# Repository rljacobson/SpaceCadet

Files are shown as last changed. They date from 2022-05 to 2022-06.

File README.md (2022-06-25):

# Space Cadet Keyboard Schematic and PCB

This repo contains [KiCAD](https://www.kicad.org/) source files and generated gerber files for the ["Space Cadet" keyboard](https://en.wikipedia.org/wiki/Space-cadet_keyboard), reverse engineered from reference photos in May 2022. To my knowledge, this is the first and only reproduction of this keyboard in EDA form.

### Variants

The board comes in three flavors: 

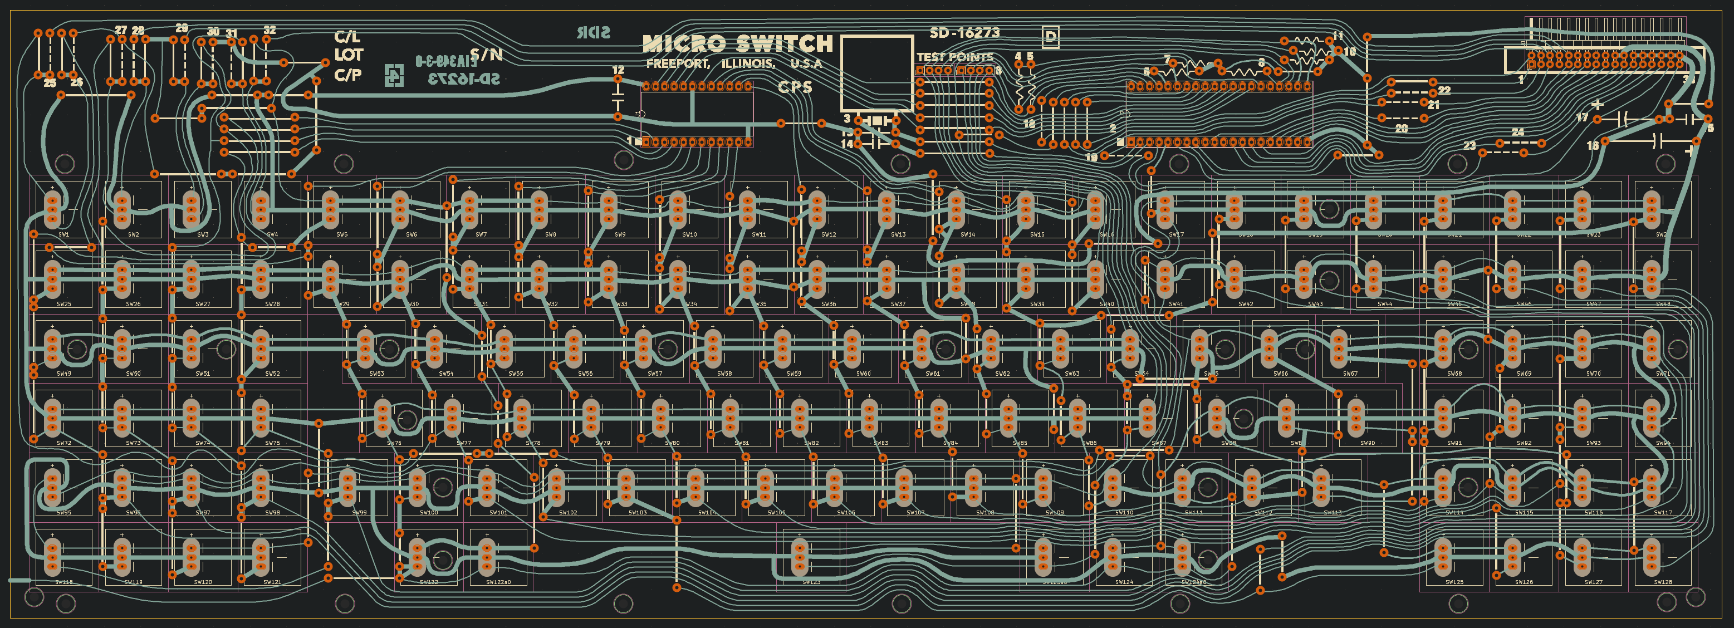
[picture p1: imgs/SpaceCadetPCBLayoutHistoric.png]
PCB Layout Historic
1. **Main branch:** An attempt at a faithful reproduction of the historic hand-drawn PCB. 
2. **Modern:** The board retains the original topology, and the footprints are in the original positions, but everything is drawn in the style of a modern PCB. 
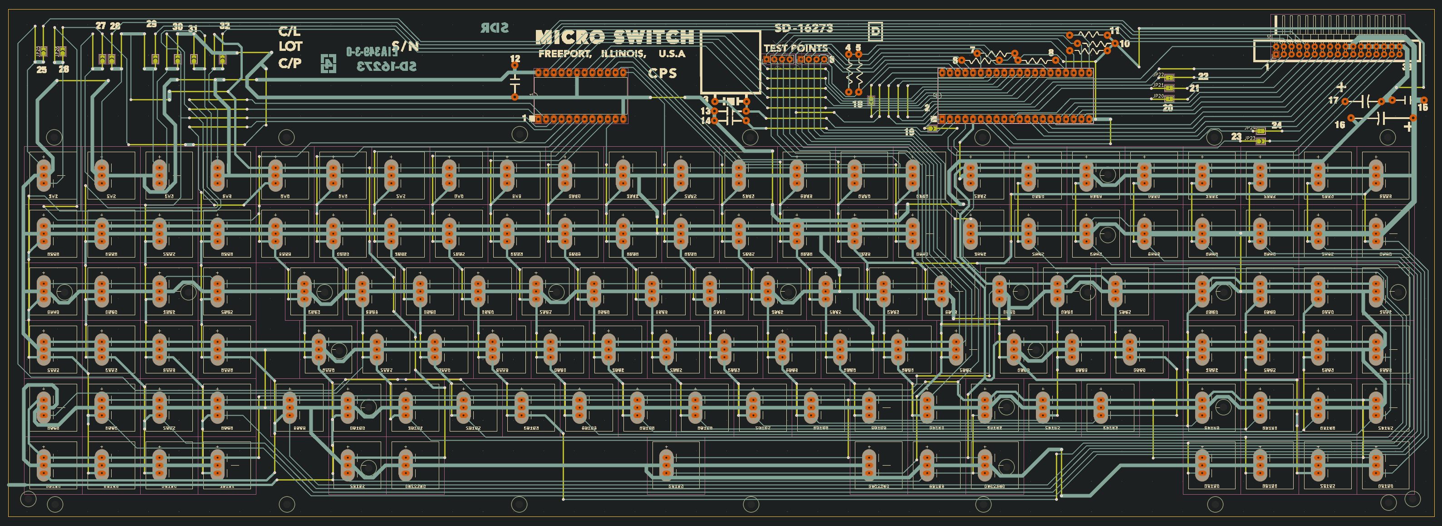
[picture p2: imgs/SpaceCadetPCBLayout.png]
SpaceCadetPCBLayout
   
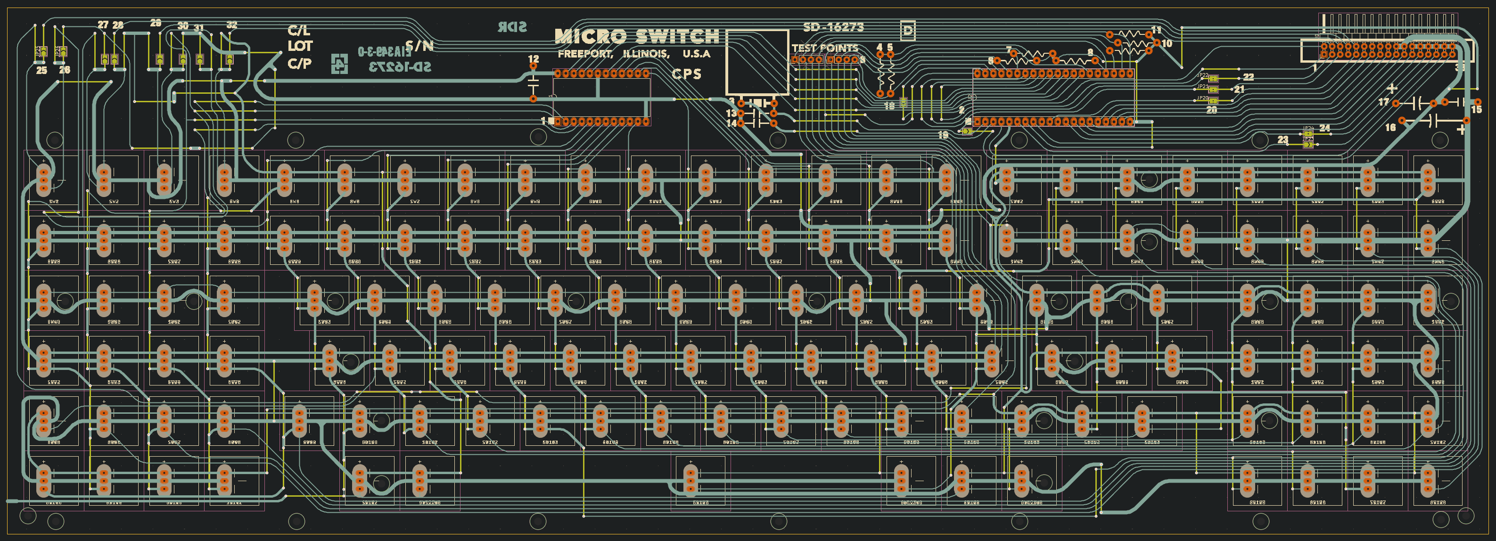
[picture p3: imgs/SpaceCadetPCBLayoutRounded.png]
SpaceCadetPCBLayoutRounded
3. **Modern Rounded:** The modern version processed with the *Round Tracks* plugin for KiCAD, which gives the board a hand-drawn aesthetic. 

Variations #2 and #3 are in the Modern branch.

### Reference Material

The design files were reverse engineered from a variety of reference materials. As quality reference materials were hard to get ahold of, I also include them here:

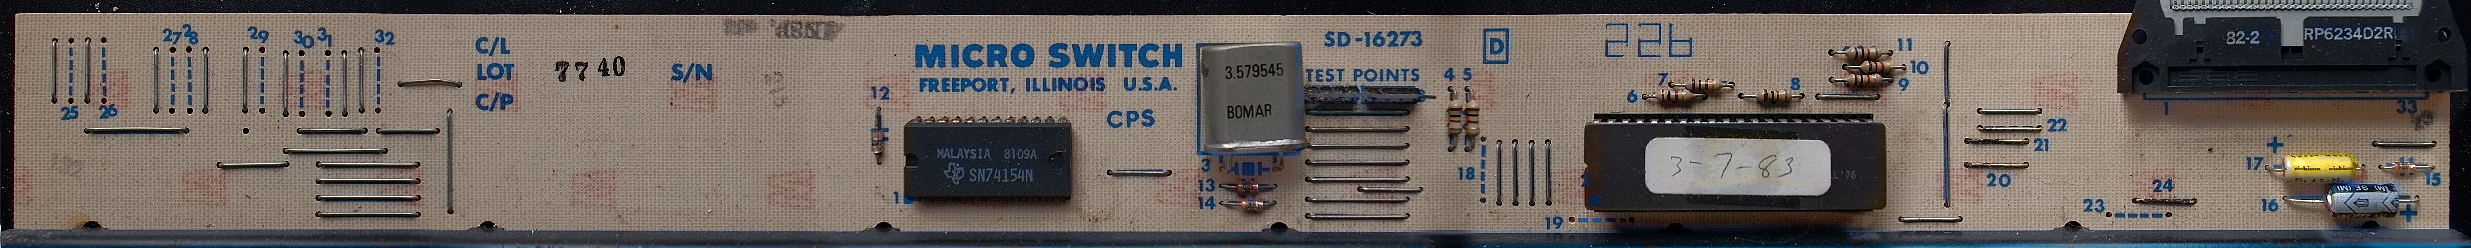
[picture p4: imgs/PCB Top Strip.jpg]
PCB Top Strip


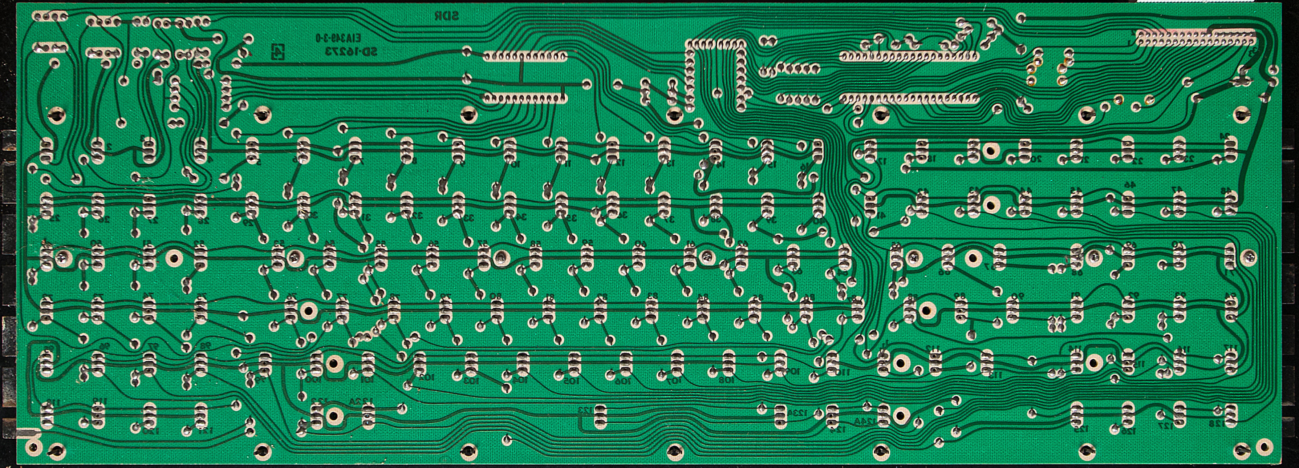
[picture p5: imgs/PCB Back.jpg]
PCB Back


I am unable to find a reference for the entire front of the PCB without the key switches and panel obscuring most of the board. From the traces and vias visible on the back of the PCB,  there are clearly many jumper wires on the front of the PCB the locations of which are easily determined.

## Other interesting things

### Micro Switch SD Series model E footprint and symbol

* [MicroSwitch_SD_Series_E.kicad_sym](MicroSwitch_SD_Series_E.kicad_sym)
* [MicroSwitch_SD_Series_E.kicad_mod](MicroSwitch_SD_Series_E.kicad_mod)

# Open Hardware License

These source files are Copyright © 2022 by Robert Jacobson. They are distributed under the terms of the CERN Open Hardware – Permissive license, also called the CERN-OHL-P v2 license. See [LICENSE.txt](LICENSE.txt) for details.

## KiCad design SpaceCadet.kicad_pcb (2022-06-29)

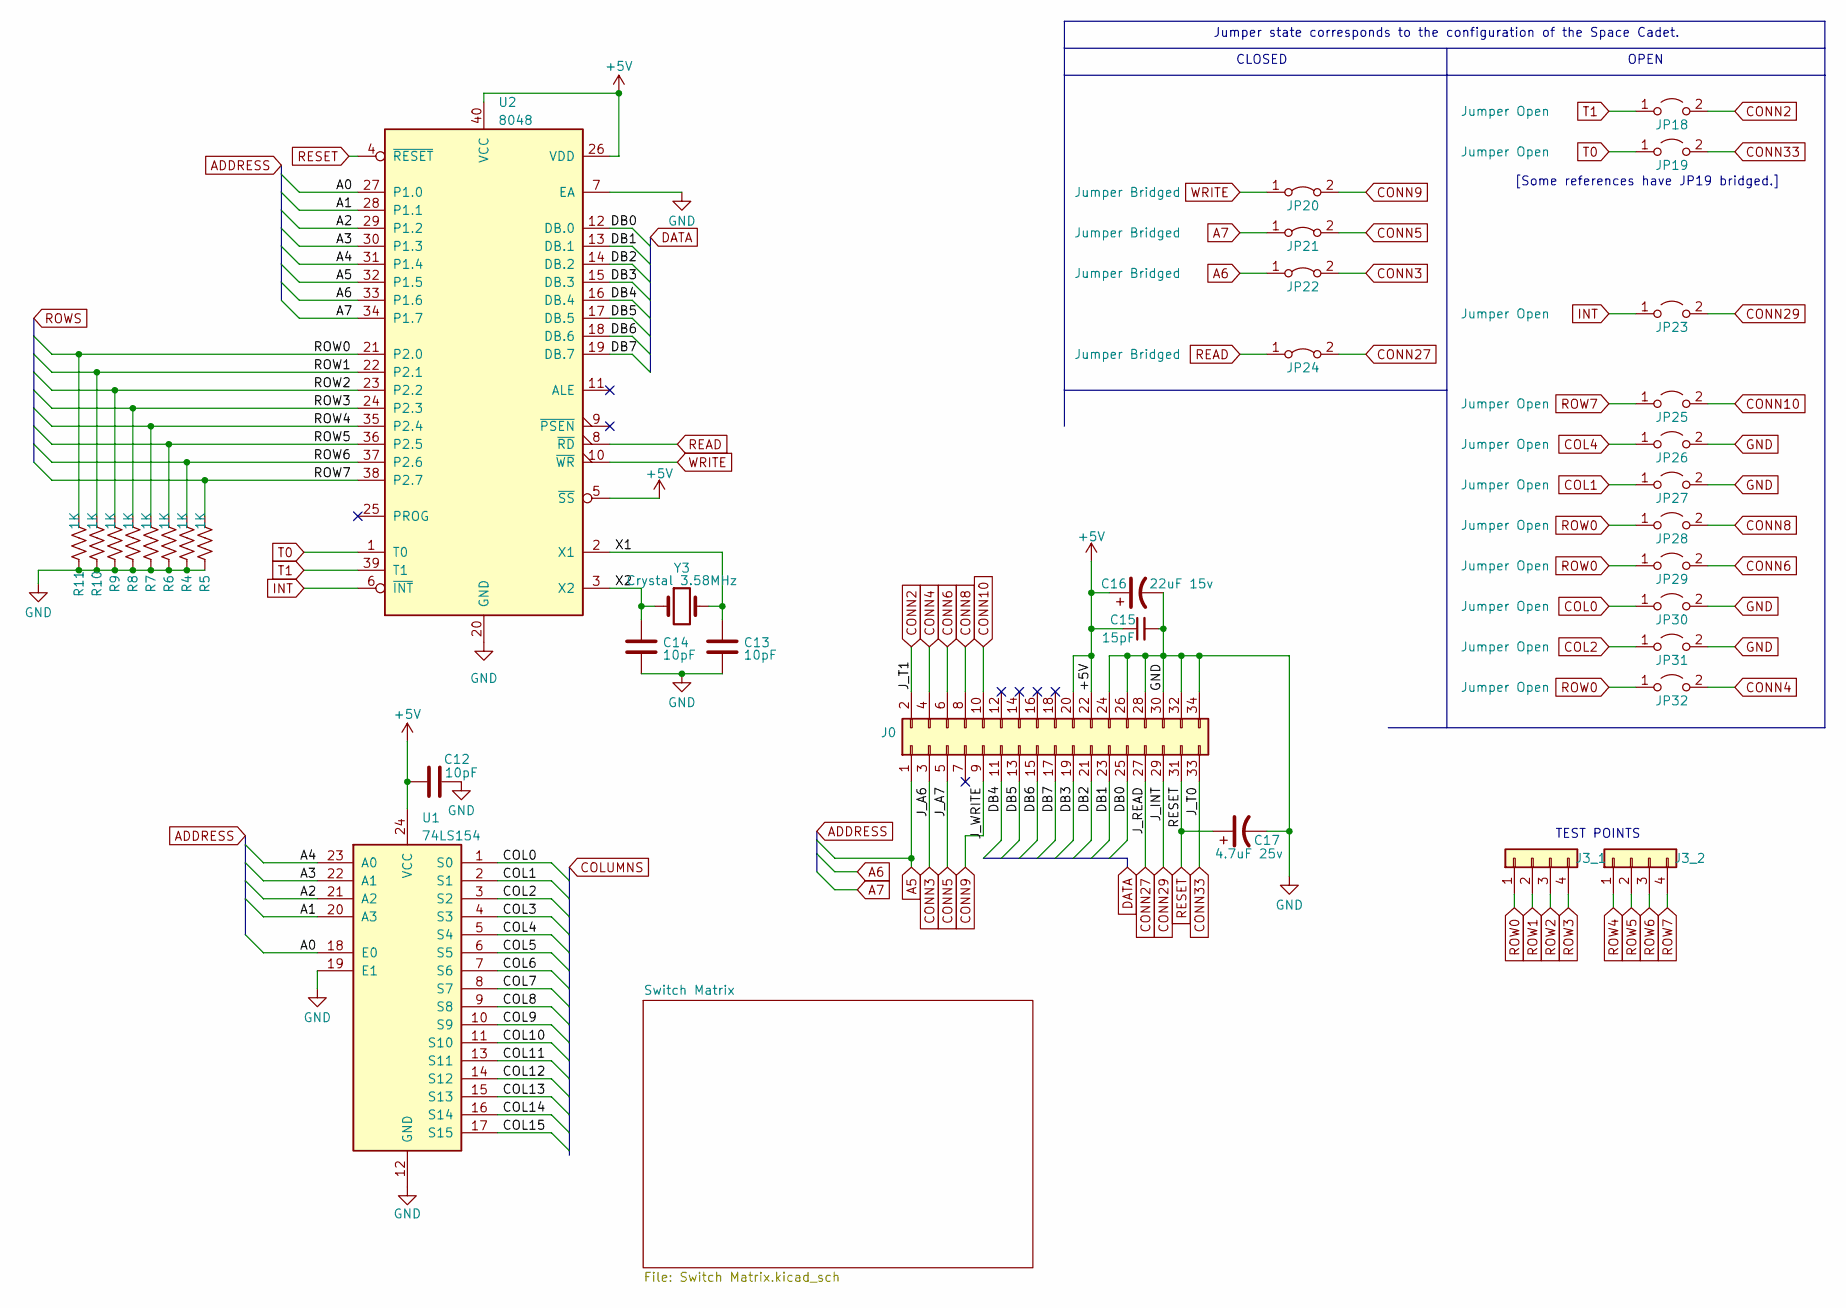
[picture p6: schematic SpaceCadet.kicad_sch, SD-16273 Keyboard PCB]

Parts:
C12, C13, C14: 10pF; Two_Pad_Through_Hole_10.4mm
C15: 15pF; Two_Pad_Through_Hole_10.4mm
C16: 22uF 15v; Two_Pad_Through_Hole_20mm
C17: 4.7uF 25v; Two_Pad_Through_Hole_12mm
J0: Conn_02x17_Odd_Even; PinHeader_2x17_P2.54mm_Horizontal
J3_1, J3_2: Conn_01x04; PinHeader_1x04_P2.54mm_Vertical
JP18, JP19, JP23, JP25, JP26, JP27, JP28, JP29, JP30, JP31, JP32: Jumper Open; SolderJumper-2_P1.3mm_Open_TrianglePad1.0x1.5mm
JP20, JP21, JP22, JP24: Jumper Bridged; SolderJumper-2_P1.3mm_Bridged2Bar_Pad1.0x1.5mm
R4, R5, R6, R7, R8, R9, R10, R11: 1K; Two_Pad_Through_Hole_12.4mm
U1: 74LS154; DIP-24_W15.24mm_LongPads
U2: 8048; DIP-40_W15.24mm_Socket_LongPads
Y3: Crystal 3.58MHz; Two_Pad_Through_Hole_10.4mm

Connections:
+5V: C12.1, C15.1, C16.1, J0.20, J0.22, U1.24 (VCC), U2.5 (~SS), U2.26 (VDD), U2.40 (VCC); also elsewhere on the board
/A0: U1.18 (E0), U2.27 (P1.0)
/A1: U1.20 (A3), U2.28 (P1.1)
/A2: U1.21 (A2), U2.29 (P1.2)
/A3: U1.22 (A1), U2.30 (P1.3)
/A4: U1.23 (A0), U2.31 (P1.4)
/COL3: U1.4 (S3)
/COL5: U1.6 (S5)
/COL6: U1.7 (S6)
/COL7: U1.8 (S7)
/COL8: U1.9 (S8)
/COL9: U1.10 (S9)
/COL10: U1.11 (S10)
/COL11: U1.13 (S11)
/COL12: U1.14 (S12)
/COL13: U1.15 (S13)
/COL14: U1.16 (S14)
/COL15: U1.17 (S15)
/DB0: J0.25, U2.12 (DB.0)
/DB1: J0.23, U2.13 (DB.1)
/DB2: J0.21, U2.14 (DB.2)
/DB3: J0.19, U2.15 (DB.3)
/DB4: J0.11, U2.16 (DB.4)
/DB5: J0.13, U2.17 (DB.5)
/DB6: J0.15, U2.18 (DB.6)
/DB7: J0.17, U2.19 (DB.7)
/X1: C13.1, U2.2 (X1), Y3.2
/X2: C14.1, U2.3 (X2), Y3.1
A5: J0.1, U2.32 (P1.5)
A6: U2.33 (P1.6)
A7: U2.34 (P1.7)
COL0: U1.1 (S0); also elsewhere on the board
COL1: U1.2 (S1); also elsewhere on the board
COL2: U1.3 (S2); also elsewhere on the board
COL4: U1.5 (S4); also elsewhere on the board
CONN2: J0.2, JP18.2 (B)
CONN3: J0.3, JP22.2 (B)
CONN4: J0.4, JP32.2 (B)
CONN5: J0.5, JP21.2 (B)
CONN6: J0.6, JP29.2 (B)
CONN8: J0.8, JP28.2 (B)
CONN9: J0.9, JP20.2 (B)
CONN10: J0.10, JP25.2 (B)
CONN27: J0.27, JP24.2 (B)
CONN29: J0.29, JP23.2 (B)
CONN33: J0.33, JP19.2 (B)
GND: C12.2, C13.2, C14.2, C15.2, C16.2, C17.2, J0.24, J0.26, J0.28, J0.30, J0.32, J0.34, R4.1, R5.1, R6.1, R7.1, R8.1, R9.1, R10.1, R11.1, U1.12 (GND), U1.19 (E1), U2.7 (EA), U2.20 (GND)
INT: JP23.1 (A), U2.6 (~INT)
unnamed: JP26.2 (B), JP27.2 (B), JP30.2 (B), JP31.2 (B)
READ: JP24.1 (A), U2.8 (~RD)
RESET: C17.1, J0.31, U2.4 (~RESET)
ROW0: J3_1.1, JP28.1 (A), JP29.1 (A), JP32.1 (A), R11.2, U2.21 (P2.0); also elsewhere on the board
ROW1: J3_1.2, R10.2, U2.22 (P2.1); also elsewhere on the board
ROW2: J3_1.3, R9.2, U2.23 (P2.2); also elsewhere on the board
ROW3: J3_1.4, R8.2, U2.24 (P2.3); also elsewhere on the board
ROW4: J3_2.1, R7.2, U2.35 (P2.4); also elsewhere on the board
ROW5: J3_2.2, R6.2, U2.36 (P2.5); also elsewhere on the board
ROW6: J3_2.3, R4.2, U2.37 (P2.6); also elsewhere on the board
ROW7: J3_2.4, JP25.1 (A), R5.2, U2.38 (P2.7); also elsewhere on the board
T0: JP19.1 (A), U2.1 (T0)
T1: JP18.1 (A), U2.39 (T1)
WRITE: JP20.1 (A), U2.10 (~WR)

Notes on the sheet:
Jumper state corresponds to the configuration of the Space Cadet.
CLOSED
TEST POINTS
[Some references have JP19 bridged.]
OPEN

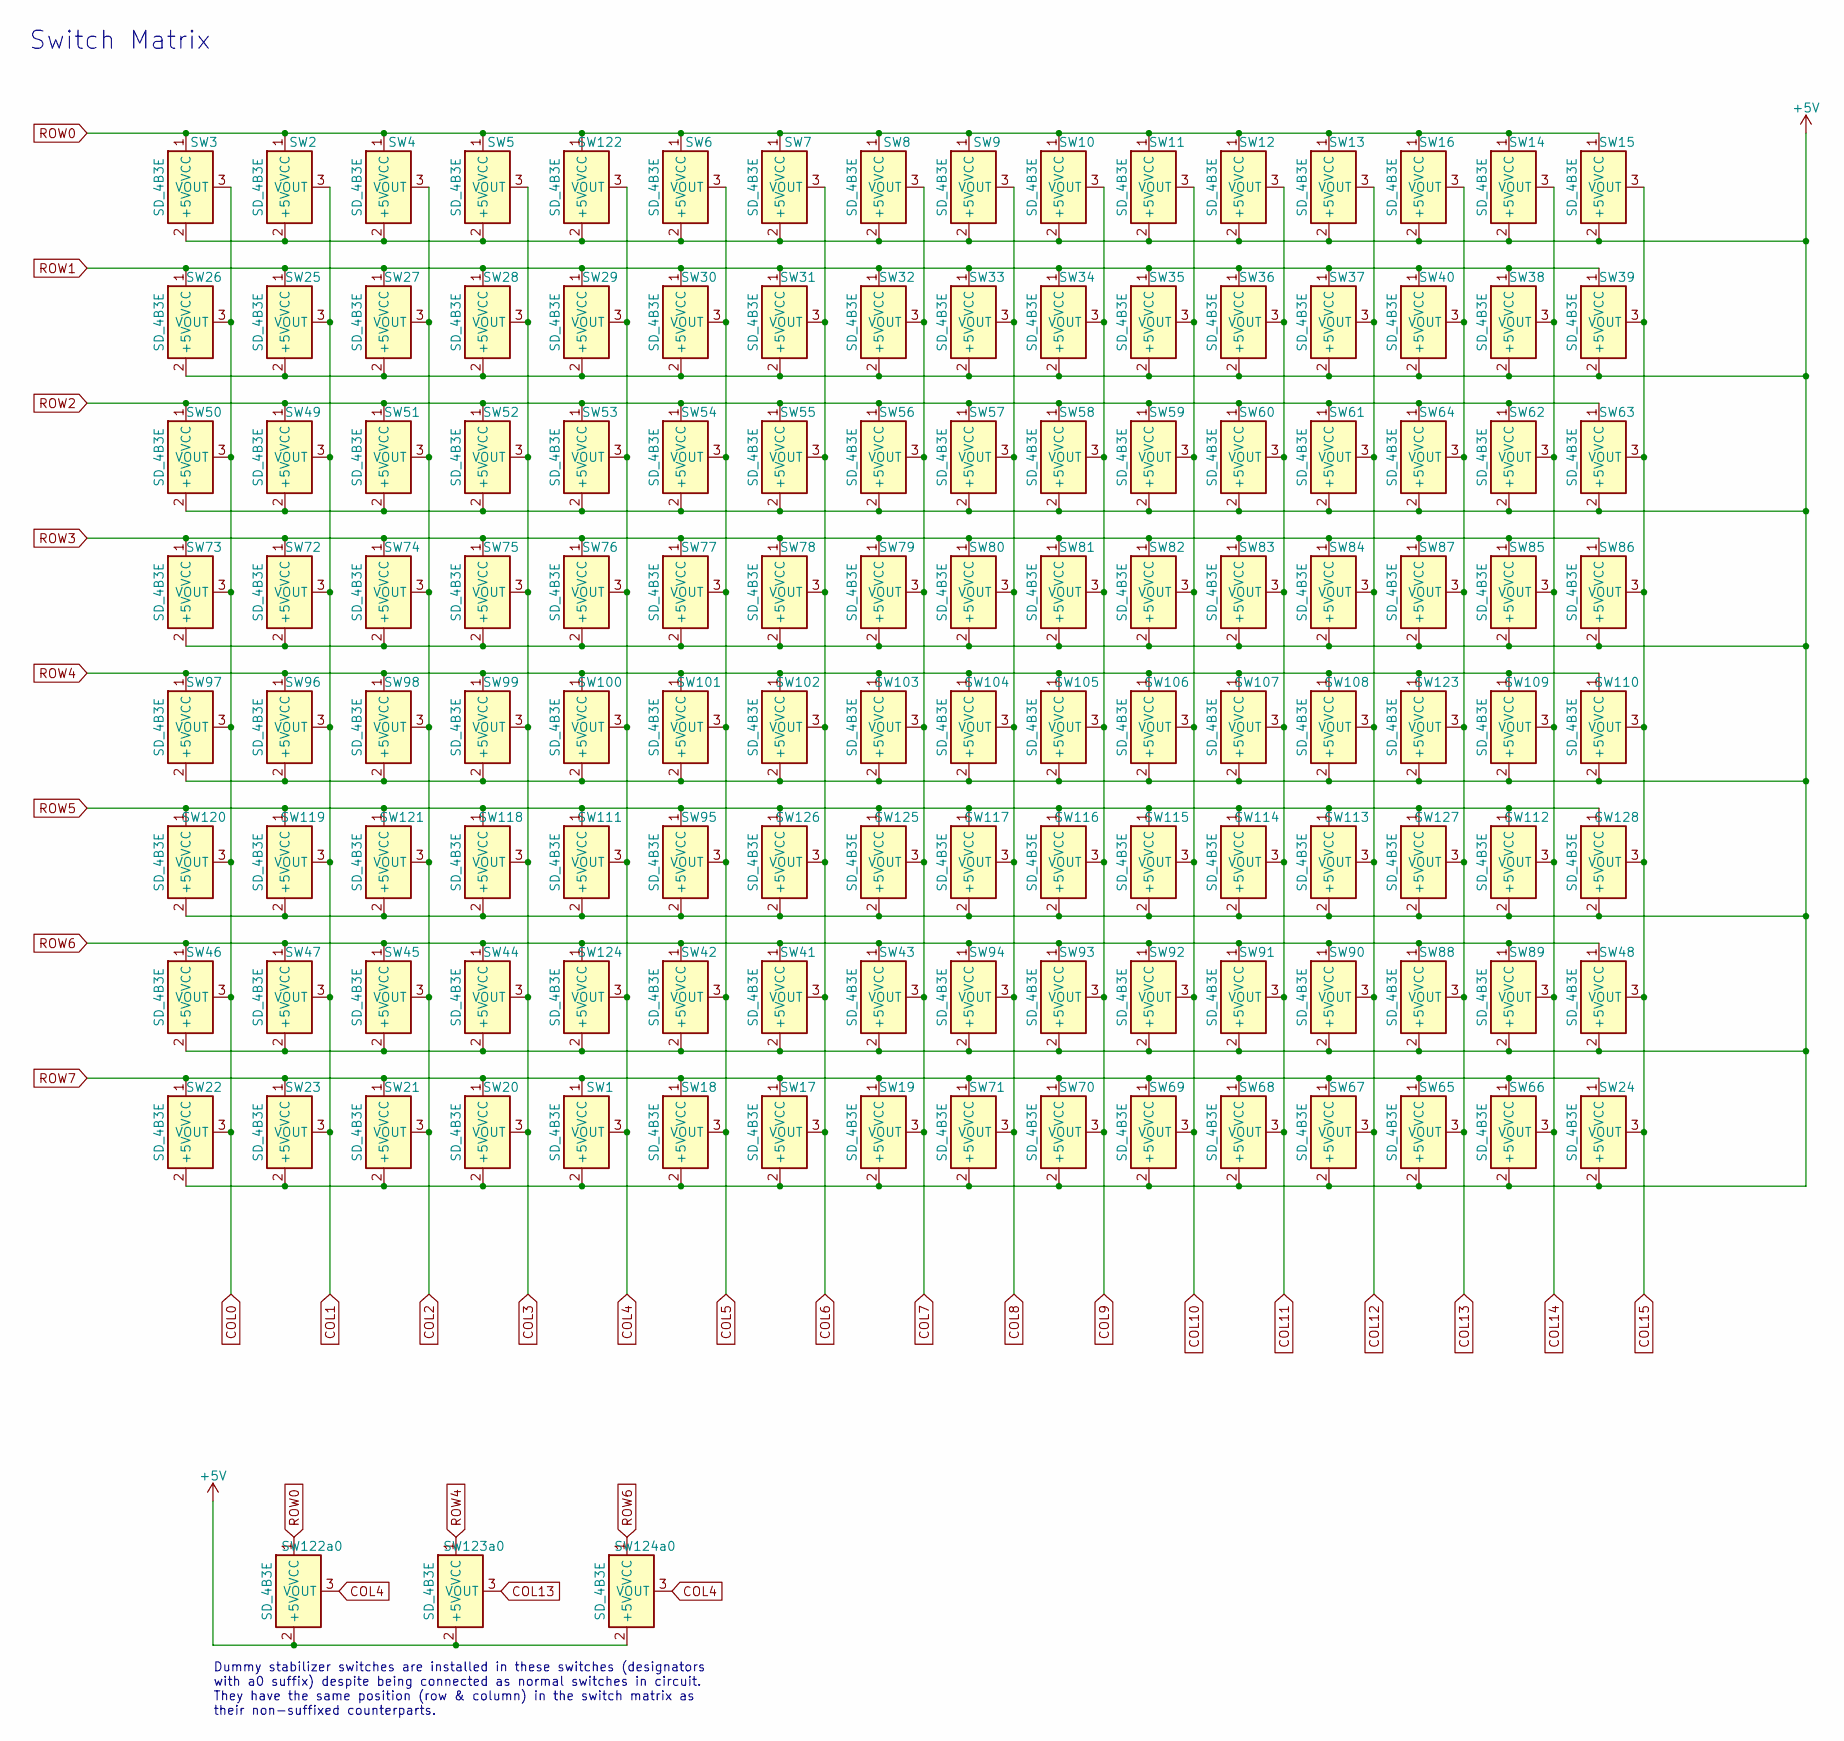
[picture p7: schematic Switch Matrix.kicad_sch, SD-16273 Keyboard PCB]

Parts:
SW1, SW2, SW3, SW4, SW5, SW6, SW7, SW8, SW9, SW10, SW11, SW12, SW13, SW14, SW15, SW16, SW17, SW18, SW19, SW20, SW21, SW22, SW23, SW24, SW25, SW26, SW27, SW28, SW29, SW30, SW31, SW32, SW33, SW34, SW35, SW36, SW37, SW38, SW39, SW40, SW41, SW42, SW43, SW44, SW45, SW46, SW47, SW48, SW49, SW50, SW51, SW52, SW53, SW54, SW55, SW56, SW57, SW58, SW59, SW60, SW61, SW62, SW63, SW64, SW65, SW66, SW67, SW68, SW69, SW70, SW71, SW72, SW73, SW74, SW75, SW76, SW77, SW78, SW79, SW80, SW81, SW82, SW83, SW84, SW85, SW86, SW87, SW88, SW89, SW90, SW91, SW92, SW93, SW94, SW95, SW96, SW97, SW98, SW99, SW100, SW101, SW102, SW103, SW104, SW105, SW106, SW107, SW108, SW109, SW110, SW111, SW112, SW113, SW114, SW115, SW116, SW117, SW118, SW119, SW120, SW121, SW122, SW122a0, SW123, SW123a0, SW124, SW124a0, SW125, SW126, SW127, SW128: SD_4B3E; MicroSwitch_SD_Series_E

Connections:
+5V: SW1.2 (+5V), SW2.2 (+5V), SW3.2 (+5V), SW4.2 (+5V), SW5.2 (+5V), SW6.2 (+5V), SW7.2 (+5V), SW8.2 (+5V), SW9.2 (+5V), SW10.2 (+5V), SW11.2 (+5V), SW12.2 (+5V), SW13.2 (+5V), SW14.2 (+5V), SW15.2 (+5V), SW16.2 (+5V), SW17.2 (+5V), SW18.2 (+5V), SW19.2 (+5V), SW20.2 (+5V), SW21.2 (+5V), SW22.2 (+5V), SW23.2 (+5V), SW24.2 (+5V), SW25.2 (+5V), SW26.2 (+5V), SW27.2 (+5V), SW28.2 (+5V), SW29.2 (+5V), SW30.2 (+5V), SW31.2 (+5V), SW32.2 (+5V), SW33.2 (+5V), SW34.2 (+5V), SW35.2 (+5V), SW36.2 (+5V), SW37.2 (+5V), SW38.2 (+5V), SW39.2 (+5V), SW40.2 (+5V), SW41.2 (+5V), SW42.2 (+5V), SW43.2 (+5V), SW44.2 (+5V), SW45.2 (+5V), SW46.2 (+5V), SW47.2 (+5V), SW48.2 (+5V), SW49.2 (+5V), SW50.2 (+5V), SW51.2 (+5V), SW52.2 (+5V), SW53.2 (+5V), SW54.2 (+5V), SW55.2 (+5V), SW56.2 (+5V), SW57.2 (+5V), SW58.2 (+5V), SW59.2 (+5V), SW60.2 (+5V), SW61.2 (+5V), SW62.2 (+5V), SW63.2 (+5V), SW64.2 (+5V), SW65.2 (+5V), SW66.2 (+5V), SW67.2 (+5V), SW68.2 (+5V), SW69.2 (+5V), SW70.2 (+5V), SW71.2 (+5V), SW72.2 (+5V), SW73.2 (+5V), SW74.2 (+5V), SW75.2 (+5V), SW76.2 (+5V), SW77.2 (+5V), SW78.2 (+5V), SW79.2 (+5V), SW80.2 (+5V), SW81.2 (+5V), SW82.2 (+5V), SW83.2 (+5V), SW84.2 (+5V), SW85.2 (+5V), SW86.2 (+5V), SW87.2 (+5V), SW88.2 (+5V), SW89.2 (+5V), SW90.2 (+5V), SW91.2 (+5V), SW92.2 (+5V), SW93.2 (+5V), SW94.2 (+5V), SW95.2 (+5V), SW96.2 (+5V), SW97.2 (+5V), SW98.2 (+5V), SW99.2 (+5V), SW100.2 (+5V), SW101.2 (+5V), SW102.2 (+5V), SW103.2 (+5V), SW104.2 (+5V), SW105.2 (+5V), SW106.2 (+5V), SW107.2 (+5V), SW108.2 (+5V), SW109.2 (+5V), SW110.2 (+5V), SW111.2 (+5V), SW112.2 (+5V), SW113.2 (+5V), SW114.2 (+5V), SW115.2 (+5V), SW116.2 (+5V), SW117.2 (+5V), SW118.2 (+5V), SW119.2 (+5V), SW120.2 (+5V), SW121.2 (+5V), SW122.2 (+5V), SW122a0.2 (+5V), SW123.2 (+5V), SW123a0.2 (+5V), SW124.2 (+5V), SW124a0.2 (+5V), SW125.2 (+5V), SW126.2 (+5V), SW127.2 (+5V), SW128.2 (+5V); also elsewhere on the board
COL0: SW3.3 (VOUT), SW22.3 (VOUT), SW26.3 (VOUT), SW46.3 (VOUT), SW50.3 (VOUT), SW73.3 (VOUT), SW97.3 (VOUT), SW120.3 (VOUT); also elsewhere on the board
COL1: SW2.3 (VOUT), SW23.3 (VOUT), SW25.3 (VOUT), SW47.3 (VOUT), SW49.3 (VOUT), SW72.3 (VOUT), SW96.3 (VOUT), SW119.3 (VOUT); also elsewhere on the board
COL2: SW4.3 (VOUT), SW21.3 (VOUT), SW27.3 (VOUT), SW45.3 (VOUT), SW51.3 (VOUT), SW74.3 (VOUT), SW98.3 (VOUT), SW121.3 (VOUT); also elsewhere on the board
COL3: SW5.3 (VOUT), SW20.3 (VOUT), SW28.3 (VOUT), SW44.3 (VOUT), SW52.3 (VOUT), SW75.3 (VOUT), SW99.3 (VOUT), SW118.3 (VOUT)
COL4: SW1.3 (VOUT), SW29.3 (VOUT), SW53.3 (VOUT), SW76.3 (VOUT), SW100.3 (VOUT), SW111.3 (VOUT), SW122.3 (VOUT), SW122a0.3 (VOUT), SW124.3 (VOUT), SW124a0.3 (VOUT); also elsewhere on the board
COL5: SW6.3 (VOUT), SW18.3 (VOUT), SW30.3 (VOUT), SW42.3 (VOUT), SW54.3 (VOUT), SW77.3 (VOUT), SW95.3 (VOUT), SW101.3 (VOUT)
COL6: SW7.3 (VOUT), SW17.3 (VOUT), SW31.3 (VOUT), SW41.3 (VOUT), SW55.3 (VOUT), SW78.3 (VOUT), SW102.3 (VOUT), SW126.3 (VOUT)
COL7: SW8.3 (VOUT), SW19.3 (VOUT), SW32.3 (VOUT), SW43.3 (VOUT), SW56.3 (VOUT), SW79.3 (VOUT), SW103.3 (VOUT), SW125.3 (VOUT)
COL8: SW9.3 (VOUT), SW33.3 (VOUT), SW57.3 (VOUT), SW71.3 (VOUT), SW80.3 (VOUT), SW94.3 (VOUT), SW104.3 (VOUT), SW117.3 (VOUT)
COL9: SW10.3 (VOUT), SW34.3 (VOUT), SW58.3 (VOUT), SW70.3 (VOUT), SW81.3 (VOUT), SW93.3 (VOUT), SW105.3 (VOUT), SW116.3 (VOUT)
COL10: SW11.3 (VOUT), SW35.3 (VOUT), SW59.3 (VOUT), SW69.3 (VOUT), SW82.3 (VOUT), SW92.3 (VOUT), SW106.3 (VOUT), SW115.3 (VOUT)
COL11: SW12.3 (VOUT), SW36.3 (VOUT), SW60.3 (VOUT), SW68.3 (VOUT), SW83.3 (VOUT), SW91.3 (VOUT), SW107.3 (VOUT), SW114.3 (VOUT)
COL12: SW13.3 (VOUT), SW37.3 (VOUT), SW61.3 (VOUT), SW67.3 (VOUT), SW84.3 (VOUT), SW90.3 (VOUT), SW108.3 (VOUT), SW113.3 (VOUT)
COL13: SW16.3 (VOUT), SW40.3 (VOUT), SW64.3 (VOUT), SW65.3 (VOUT), SW87.3 (VOUT), SW88.3 (VOUT), SW123.3 (VOUT), SW123a0.3 (VOUT), SW127.3 (VOUT)
COL14: SW14.3 (VOUT), SW38.3 (VOUT), SW62.3 (VOUT), SW66.3 (VOUT), SW85.3 (VOUT), SW89.3 (VOUT), SW109.3 (VOUT), SW112.3 (VOUT)
COL15: SW15.3 (VOUT), SW24.3 (VOUT), SW39.3 (VOUT), SW48.3 (VOUT), SW63.3 (VOUT), SW86.3 (VOUT), SW110.3 (VOUT), SW128.3 (VOUT)
ROW0: SW2.1 (VCC), SW3.1 (VCC), SW4.1 (VCC), SW5.1 (VCC), SW6.1 (VCC), SW7.1 (VCC), SW8.1 (VCC), SW9.1 (VCC), SW10.1 (VCC), SW11.1 (VCC), SW12.1 (VCC), SW13.1 (VCC), SW14.1 (VCC), SW15.1 (VCC), SW16.1 (VCC), SW122.1 (VCC), SW122a0.1 (VCC); also elsewhere on the board
ROW1: SW25.1 (VCC), SW26.1 (VCC), SW27.1 (VCC), SW28.1 (VCC), SW29.1 (VCC), SW30.1 (VCC), SW31.1 (VCC), SW32.1 (VCC), SW33.1 (VCC), SW34.1 (VCC), SW35.1 (VCC), SW36.1 (VCC), SW37.1 (VCC), SW38.1 (VCC), SW39.1 (VCC), SW40.1 (VCC); also elsewhere on the board
ROW2: SW49.1 (VCC), SW50.1 (VCC), SW51.1 (VCC), SW52.1 (VCC), SW53.1 (VCC), SW54.1 (VCC), SW55.1 (VCC), SW56.1 (VCC), SW57.1 (VCC), SW58.1 (VCC), SW59.1 (VCC), SW60.1 (VCC), SW61.1 (VCC), SW62.1 (VCC), SW63.1 (VCC), SW64.1 (VCC); also elsewhere on the board
ROW3: SW72.1 (VCC), SW73.1 (VCC), SW74.1 (VCC), SW75.1 (VCC), SW76.1 (VCC), SW77.1 (VCC), SW78.1 (VCC), SW79.1 (VCC), SW80.1 (VCC), SW81.1 (VCC), SW82.1 (VCC), SW83.1 (VCC), SW84.1 (VCC), SW85.1 (VCC), SW86.1 (VCC), SW87.1 (VCC); also elsewhere on the board
ROW4: SW96.1 (VCC), SW97.1 (VCC), SW98.1 (VCC), SW99.1 (VCC), SW100.1 (VCC), SW101.1 (VCC), SW102.1 (VCC), SW103.1 (VCC), SW104.1 (VCC), SW105.1 (VCC), SW106.1 (VCC), SW107.1 (VCC), SW108.1 (VCC), SW109.1 (VCC), SW110.1 (VCC), SW123.1 (VCC), SW123a0.1 (VCC); also elsewhere on the board
ROW5: SW95.1 (VCC), SW111.1 (VCC), SW112.1 (VCC), SW113.1 (VCC), SW114.1 (VCC), SW115.1 (VCC), SW116.1 (VCC), SW117.1 (VCC), SW118.1 (VCC), SW119.1 (VCC), SW120.1 (VCC), SW121.1 (VCC), SW125.1 (VCC), SW126.1 (VCC), SW127.1 (VCC), SW128.1 (VCC); also elsewhere on the board
ROW6: SW41.1 (VCC), SW42.1 (VCC), SW43.1 (VCC), SW44.1 (VCC), SW45.1 (VCC), SW46.1 (VCC), SW47.1 (VCC), SW48.1 (VCC), SW88.1 (VCC), SW89.1 (VCC), SW90.1 (VCC), SW91.1 (VCC), SW92.1 (VCC), SW93.1 (VCC), SW94.1 (VCC), SW124.1 (VCC), SW124a0.1 (VCC); also elsewhere on the board
ROW7: SW1.1 (VCC), SW17.1 (VCC), SW18.1 (VCC), SW19.1 (VCC), SW20.1 (VCC), SW21.1 (VCC), SW22.1 (VCC), SW23.1 (VCC), SW24.1 (VCC), SW65.1 (VCC), SW66.1 (VCC), SW67.1 (VCC), SW68.1 (VCC), SW69.1 (VCC), SW70.1 (VCC), SW71.1 (VCC); also elsewhere on the board

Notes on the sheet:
Switch Matrix
Dummy stabilizer switches are installed in these switches (designators with a0 suffix) despite being connected as normal switches in circuit. They have the same position (row & column) in the switch matrix as their non-suffixed counterparts.

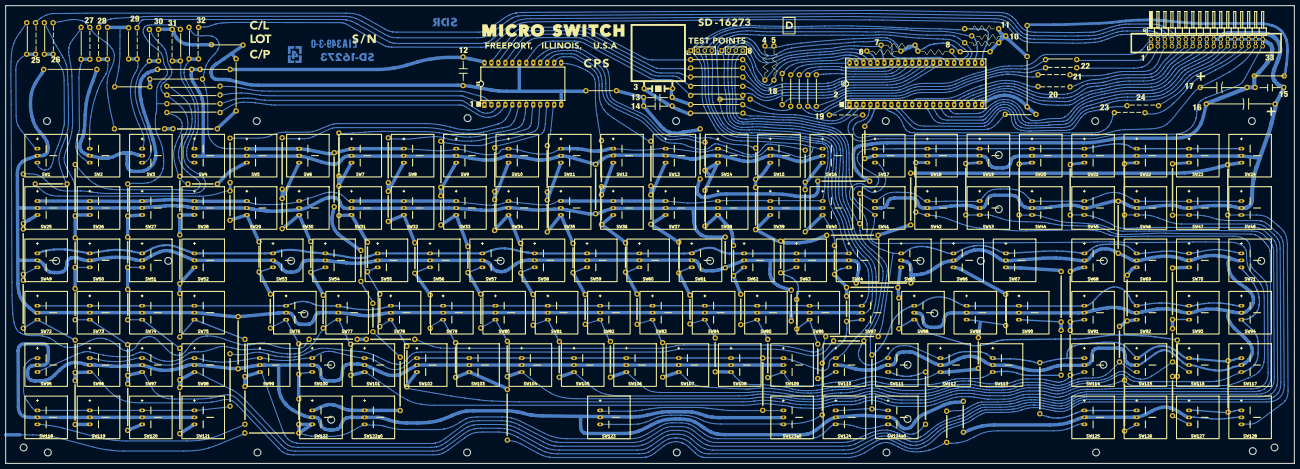
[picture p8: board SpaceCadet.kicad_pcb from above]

Board: 2 copper layers, 469.0 x 166.6 mm, 151 parts (0 on the bottom side), 43 nets.

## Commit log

2022-05-23 Initial commit.
    [SpaceCadet.kicad_pcb, SpaceCadet.kicad_sch, Switch Matrix.kicad_sch]
2022-06-04 Brought over bug fixes from other branch. Fixed some paths to be closer to original. Fixed path going through mount hole.
    [SpaceCadet.kicad_pcb, SpaceCadet.kicad_sch, Switch Matrix.kicad_sch]
2022-06-06 Minor edits
    [SpaceCadet.kicad_pcb]
2022-06-13 Added traces, jumpers to front to use DRC. Fixed lots of real and imaginary DRC errors/warnings.
    [SpaceCadet.kicad_pcb, SpaceCadet.kicad_sch]
2022-06-13 Now one-sided board.
    [SpaceCadet-B_Cu.gbr, SpaceCadet-B_Fab.gbr, SpaceCadet-B_Mask.gbr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]
2022-06-22 Added front-side copper for constraint check. Debugged switch footprint.
    [SpaceCadet.kicad_pcb, SpaceCadet.kicad_sch]
2022-06-25 Regenerated gerbers. Removed DRC-only items.
    [SpaceCadet-B_Cu.gbr, SpaceCadet-B_Fab.gbr, SpaceCadet-B_Mask.gbr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]
2022-06-29 Updated Fab comments and generated new gerbers to reflect fabrication requirements.
    [SpaceCadet.kicad_pcb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]
